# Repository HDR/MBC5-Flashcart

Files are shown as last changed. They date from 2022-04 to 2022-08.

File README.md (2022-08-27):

## Make sure you read the License (Attribution-NonCommercial-ShareAlike 4.0 International)

Purchase on PCBWay (https://www.pcbway.com/project/shareproject/MBC5_Flashcart_2x2MB_or_4MB_FRAM_V3_244baab0.html)

If you want to support me for free (and get 5 USD in new user credit) you can use my PCBWay [Referral link](https://www.pcbway.com/setinvite.aspx?inviteid=388393) when signing up on PCBWay



Referral Link (https://www.pcbway.com/setinvite.aspx?inviteid=388393)

**Make sure you read the License!**

**BOM:**

| Reference | Part Number | Description |
|-|-|-|
| U1 | MBC5 | Harvest from original cartridge |
| U2 | [MBM29F033C/AM29F032 (4MB)](https://www.aliexpress.com/item/32711470187.html) | 4MB Flash (TSOP-40) |
| U3 | [FM18W08-SG](https://www.aliexpress.com/item/1005002024061036.html) | 256Kb FRAM (SOIC-28) |
| U4 | [74LVC1G332GV,125](https://www.nexperia.com/products/analog-logic-ics/control-logic/gates/or-gates/74LVC1G332GV.html) | 3-Input OR Gate (TSOP-6) |
| C1, C2, C3, C4, C5 | [CC0603KRX7R7BB104](https://lcsc.com/product-detail/Multilayer-Ceramic-Capacitors-MLCC-SMD-SMT_YAGEO-CC0603KRX7R7BB104_C108079.html) | 100nF 0603 16V |
| R1 | [RC0603JR-0710KL](https://lcsc.com/product-detail/Chip-Resistor-Surface-Mount_YAGEO-RC0603JR-0710KL_C99198.html) | 10kΩ 0603 |
| R2 | [RC0603JR-0730KL](https://lcsc.com/product-detail/Chip-Resistor-Surface-Mount_YAGEO-RC0603JR-0730KL_C113302.html) | 30kΩ 0603 |
| R3 | [RS-03K150JT](https://lcsc.com/product-detail/Chip-Resistor-Surface-Mount_FH-Guangdong-Fenghua-Advanced-Tech-RS-03K150JT_C187891.html) | 15Ω 0603 |
| D1 | [SD103AW](https://lcsc.com/product-detail/Schottky-Barrier-Diodes-SBD_Guangdong-Hottech-SD103AW_C181204.html) | SOD-123 |
| Q1 | [BC817-40,215](https://www.nexperia.com/products/bipolar-transistors/general-purpose-and-low-vcesat-bipolar-transistors/single-bipolar-transistors/single-bipolar-transistors-100-v/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) | SOT-23 |
| M1 | [Vibration Motor](https://www.aliexpress.com/item/32787320737.html) |  |
| Switch | [SP3T](https://www.aliexpress.com/item/32759020917.html) or CUS-13TB | 3 Position SP3T Switch |

*Parts & Links are suggestions, feel free to use different components as long as they have the same specs*

[Interactive BOM](https://martinrefseth.com/ibom/MBC5-Flashcart.html)

Makes use of [djedditt's](https://github.com/djedditt/s) [gamepak footprint](https://github.com/djedditt/kicad-gamepaks)

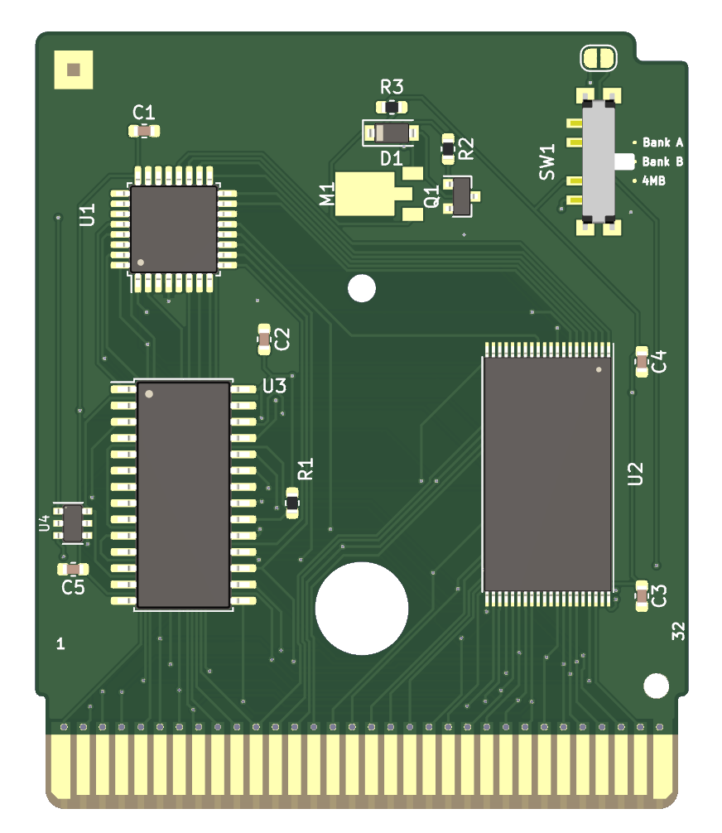
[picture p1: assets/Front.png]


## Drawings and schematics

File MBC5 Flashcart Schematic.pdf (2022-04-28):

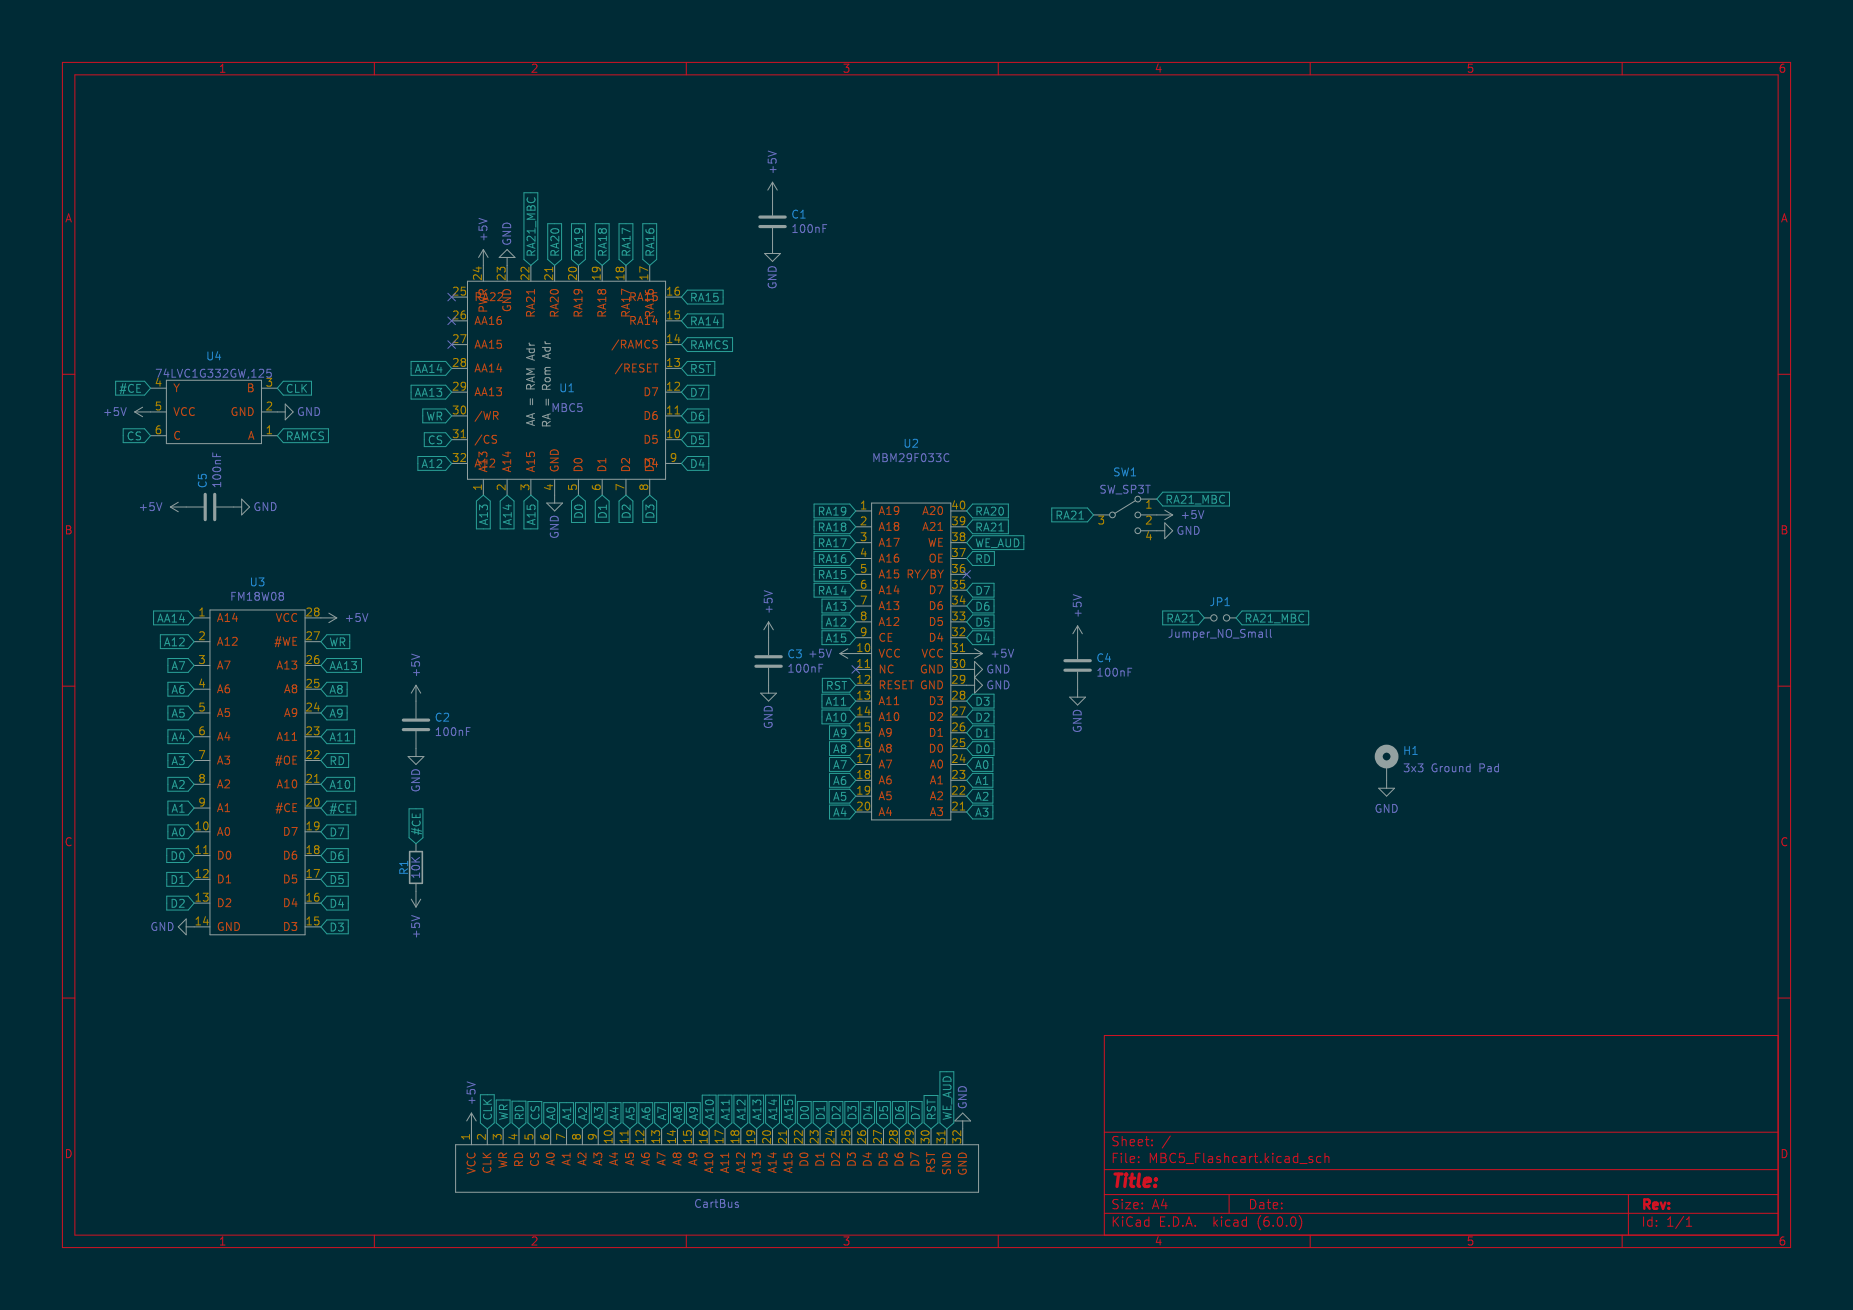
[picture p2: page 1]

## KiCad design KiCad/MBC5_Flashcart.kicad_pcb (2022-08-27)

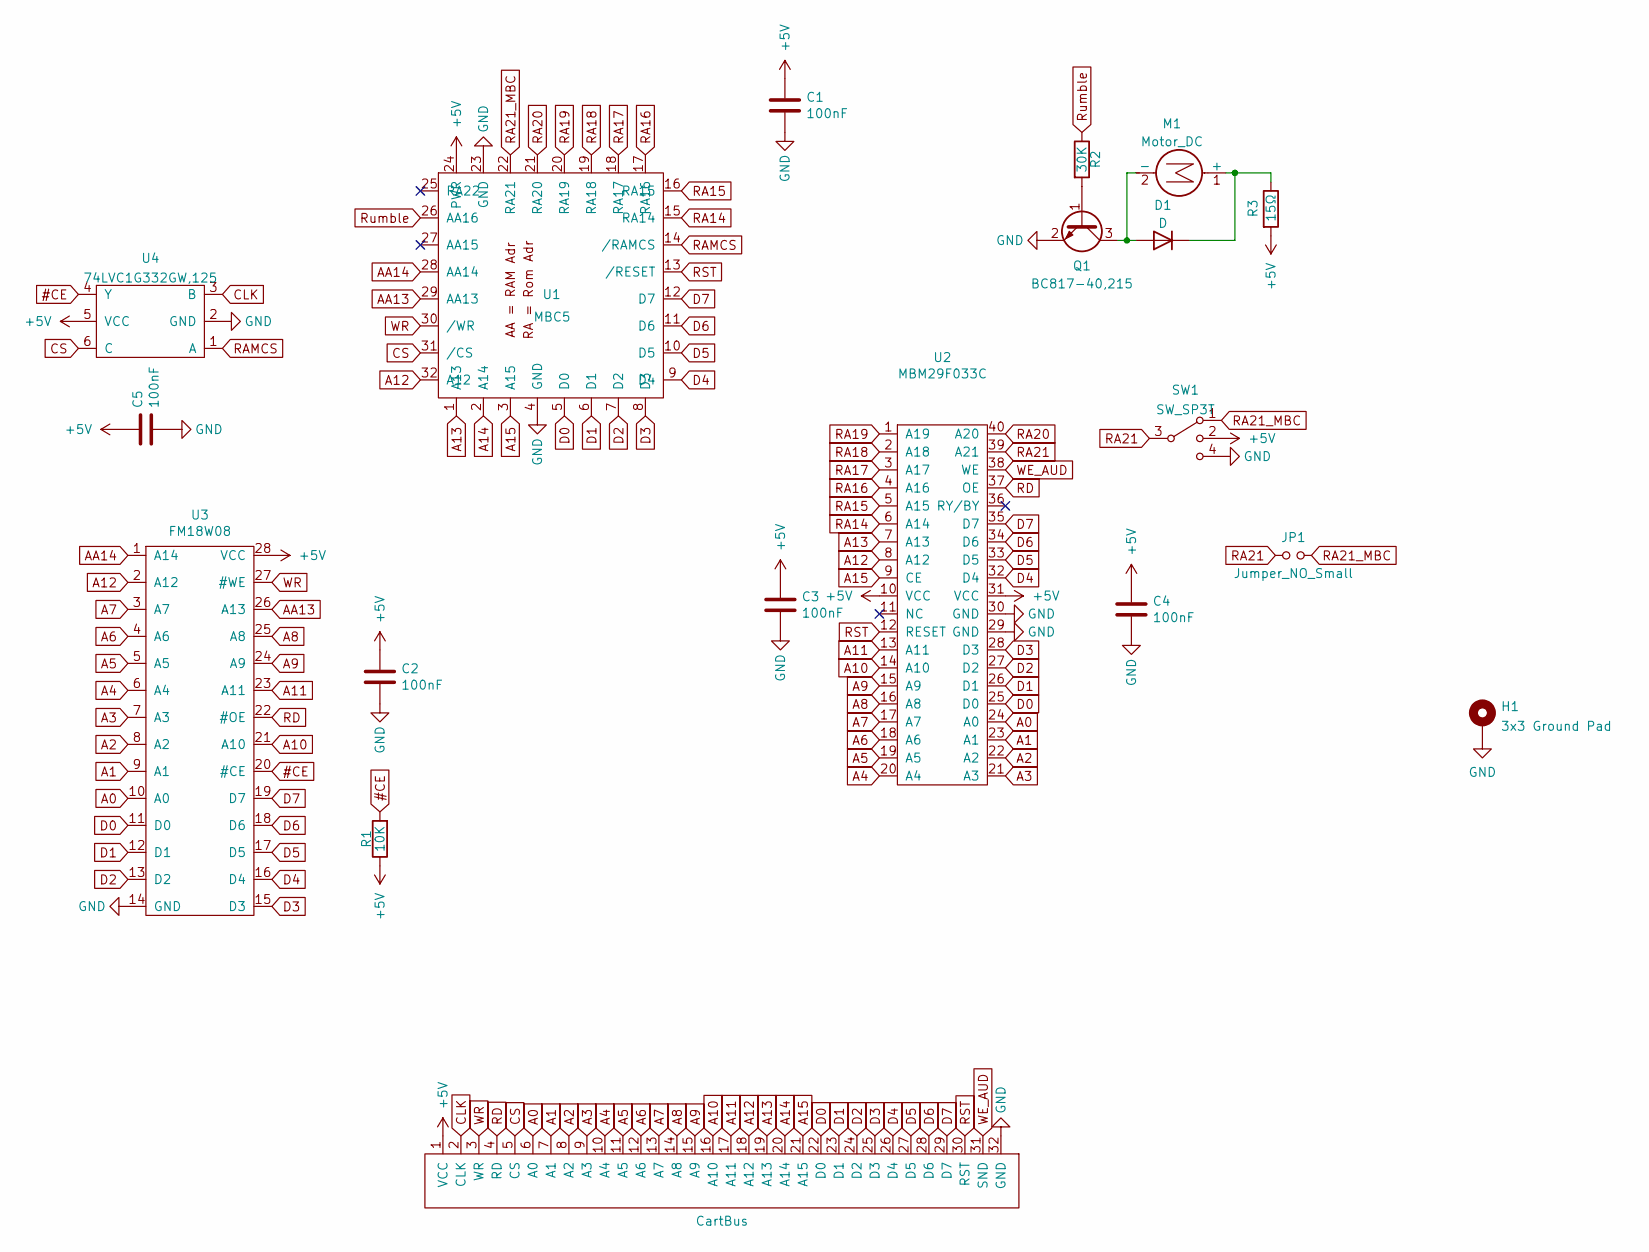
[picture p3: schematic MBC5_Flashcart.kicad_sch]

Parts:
C1, C2, C3, C4, C5: 100nF; C_0603_1608Metric
D1: D; D_SOD-123
H1: 3x3 Ground Pad; Nintendo_3x3_GNDPad
J0: CartBus; GB_Cartridge
JP1: Jumper_NO_Small; SolderJumper-2_P1.3mm_Open_RoundedPad1.0x1.5mm
M1: Motor_DC; ANDA-T1035
Q1: BC817-40,215; SOT-23
R1: 10K; R_0603_1608Metric
R2: 30K; R_0603_1608Metric
R3: 15Ω; R_0603_1608Metric
SW1: SW_SP3T; CUS-13TB-Aliex SP3T
U1: MBC5; LQFP-32_7x7mm_P0.8mm
U2: MBM29F033C; TSOP-I-40_18.4x10mm_P0.5mm
U3: FM18W08; SOIC-28W_7.5x17.9mm_P1.27mm
U4: 74LVC1G332GW,125; TSOP-6_1.65x3.05mm_P0.95mm

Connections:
#CE: R1.2, U3.20 (#CE), U4.4 (Y)
+5V: C1.1, C2.1, C3.1, C4.1, C5.1, J0.1 (VCC), R1.1, R3.2, SW1.2, U1.24 (PWR), U2.10 (VCC), U2.31 (VCC), U3.28 (VCC), U4.5 (VCC)
A0: J0.6 (A0), U2.24 (A0), U3.10 (A0)
A1: J0.7 (A1), U2.23 (A1), U3.9 (A1)
A2: J0.8 (A2), U2.22 (A2), U3.8 (A2)
A3: J0.9 (A3), U2.21 (A3), U3.7 (A3)
A4: J0.10 (A4), U2.20 (A4), U3.6 (A4)
A5: J0.11 (A5), U2.19 (A5), U3.5 (A5)
A6: J0.12 (A6), U2.18 (A6), U3.4 (A6)
A7: J0.13 (A7), U2.17 (A7), U3.3 (A7)
A8: J0.14 (A8), U2.16 (A8), U3.25 (A8)
A9: J0.15 (A9), U2.15 (A9), U3.24 (A9)
A10: J0.16 (A10), U2.14 (A10), U3.21 (A10)
A11: J0.17 (A11), U2.13 (A11), U3.23 (A11)
A12: J0.18 (A12), U1.32 (A12), U2.8 (A12), U3.2 (A12)
A13: J0.19 (A13), U1.1 (A13), U2.7 (A13)
A14: J0.20 (A14), U1.2 (A14)
A15: J0.21 (A15), U1.3 (A15), U2.9 (CE)
AA13: U1.29 (AA13), U3.26 (A13)
AA14: U1.28 (AA14), U3.1 (A14)
CLK: J0.2 (CLK~), U4.3 (B)
CS: J0.5 (CS), U1.31 (/CS), U4.6 (C)
D0: J0.22 (D0), U1.5 (D0), U2.25 (D0), U3.11 (D0)
D1: J0.23 (D1), U1.6 (D1), U2.26 (D1), U3.12 (D1)
D2: J0.24 (D2), U1.7 (D2), U2.27 (D2), U3.13 (D2)
D3: J0.25 (D3), U1.8 (D3), U2.28 (D3), U3.15 (D3)
D4: J0.26 (D4), U1.9 (D4), U2.32 (D4), U3.16 (D4)
D5: J0.27 (D5), U1.10 (D5), U2.33 (D5), U3.17 (D5)
D6: J0.28 (D6), U1.11 (D6), U2.34 (D6), U3.18 (D6)
D7: J0.29 (D7), U1.12 (D7), U2.35 (D7), U3.19 (D7)
GND: C1.2, C2.2, C3.2, C4.2, C5.2, H1.1, J0.32 (GND), Q1.2 (E), SW1.4, U1.4 (GND), U1.23 (GND), U2.29 (GND), U2.30 (GND), U3.14 (GND), U4.2 (GND); also elsewhere on the board
unnamed: D1.1 (K), M1.1 (+), R3.1
unnamed: D1.2 (A), M1.2 (-), Q1.3 (C)
unnamed: Q1.1 (B), R2.2
RA14: U1.15 (RA14), U2.6 (A14)
RA15: U1.16 (RA15), U2.5 (A15)
RA16: U1.17 (RA16), U2.4 (A16)
RA17: U1.18 (RA17), U2.3 (A17)
RA18: U1.19 (RA18), U2.2 (A18)
RA19: U1.20 (RA19), U2.1 (A19)
RA20: U1.21 (RA20), U2.40 (A20)
RA21: JP1.1, SW1.3, U2.39 (A21)
RA21_MBC: JP1.2, SW1.1, U1.22 (RA21)
RAMCS: U1.14 (/RAMCS), U4.1 (A)
RD: J0.4 (RD), U2.37 (OE), U3.22 (#OE)
RST: J0.30 (RST), U1.13 (/RESET), U2.12 (RESET)
Rumble: R2.1, U1.26 (AA16)
WE_AUD: J0.31 (SND), U2.38 (WE)
WR: J0.3 (WR), U1.30 (/WR), U3.27 (#WE)

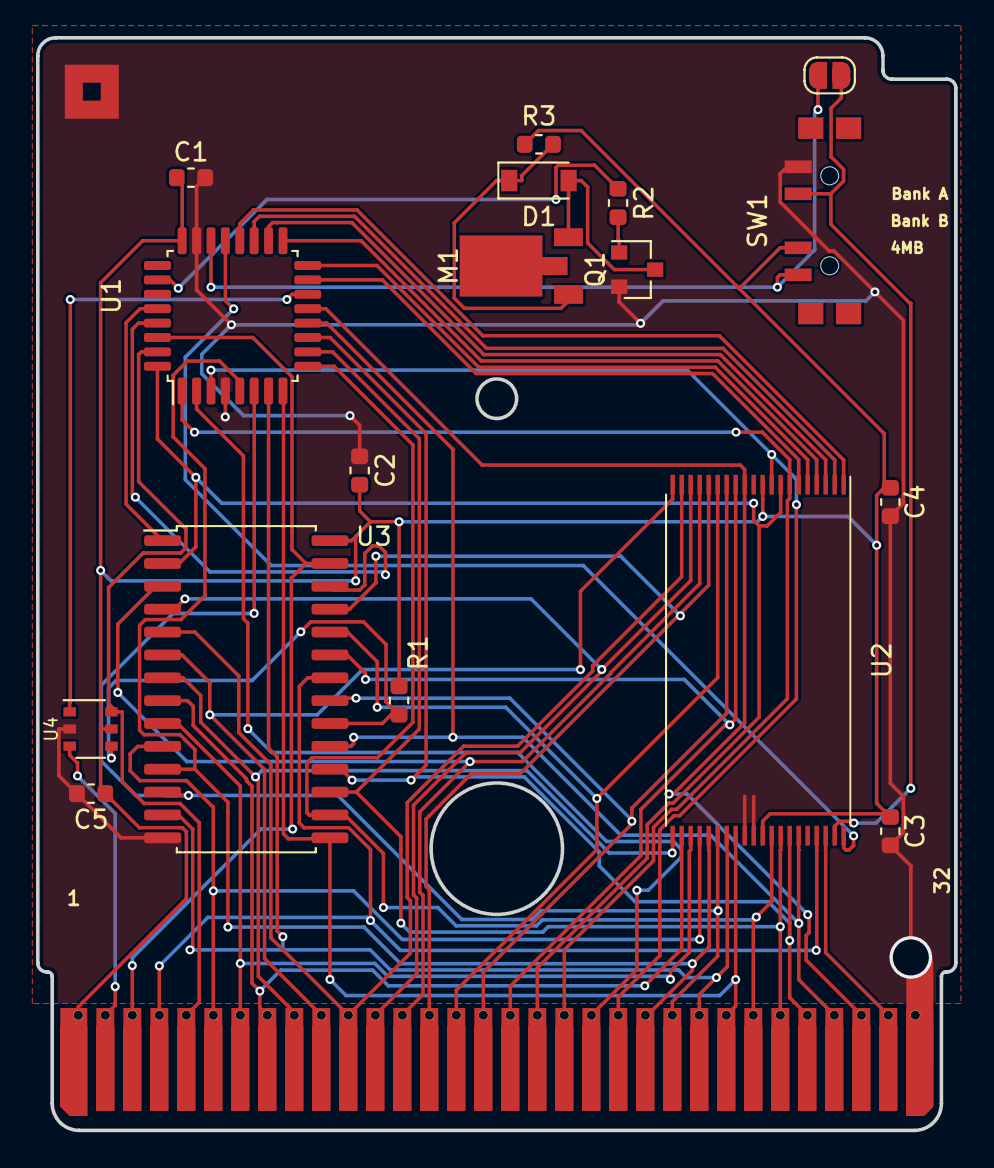
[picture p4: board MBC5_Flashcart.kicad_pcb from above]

Board: 2 copper layers, 51.0 x 60.7 mm, 20 parts (1 on the bottom side), 49 nets.

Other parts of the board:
A**: June; 08 August

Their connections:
GND: A**.1; also elsewhere on the board

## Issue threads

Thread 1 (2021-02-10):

Compatible Cart Readers?

VladAFlorea, 2021-02-10:
Hi! I have a question about the MBC5 cart. Should it be compatible with Sanni’s cart reader?

I have built a couple of the carts and am in the process of debugging an issue. I want to make sure I’m using the right cart reader before I go too far down the rabbit hole debugging.

I completely understand if this is a work in progress and that maybe I was a little too eager to build one.

Thanks for your help and great work! I have built some of your other carts and love them.

Closed 2021-02-23.

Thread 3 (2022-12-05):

PCB gerber wrong

446599, 2022-12-05:
The gerberv3 has some mistakes in the bottom side pins😊

Closed 2022-12-05.

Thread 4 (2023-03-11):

What SW1 does is

duoffice, 2023-03-11:
Hello, what is the function of the switch? SW1, thank you

HDR, 2023-03-11:
With 4MB flash you can use the switch to either have 2 2MB ROM's or a 4MB ROM

duoffice, 2023-03-12:
Do you mean that if I use 4M flash, I can use one game card as two cards by switching between BankA and BankB? If I use Flash 2M or below, the switch doesn't make sense, right? thank you

HDR, 2023-03-12:
Yes, you can flash 2 separate games to the cartridge if it has a 4MB chip, but the FRAM will be shared between the two.

Closed 2023-03-11.

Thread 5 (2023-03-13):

Do you have the circuit diagram of MBC1

duoffice, 2023-03-13:
Hello, do you have the schematic diagram of the MBC1 card？ I would like to see if I can integrate MBC5 and MBC1 chips into a PCB board, MBC1 game welded MBC1 chip, MBC5 welded MBC chip, thank you

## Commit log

2020-08-28 add kicad files
    [mbc5flash GBA.kicad_pcb, mbc5flash.kicad_pcb, mbc5flash.sch]
2022-04-28 Update to V2
    [MBC5_Flashcart.kicad_pcb, MBC5_Flashcart.kicad_sch, MBC5_Flashcart.sch]
2022-08-27 Release V3
    [MBC5_Flashcart.kicad_pcb, MBC5_Flashcart.kicad_sch]
2022-08-27 Remove R4
    [MBC5_Flashcart.kicad_pcb, MBC5_Flashcart.kicad_sch]
